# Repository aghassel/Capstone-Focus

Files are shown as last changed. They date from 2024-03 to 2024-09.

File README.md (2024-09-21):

# AI-Enhanced Glasses for Individuals with Visual and Auditory Impairments

## Overview

This project aims to develop **AI-Enhanced Glasses**, codenamed **Focus**, designed to support individuals with visual and auditory impairments. The glasses offer real-time assistance for communication, navigation, and daily tasks, promoting greater independence and enhancing the quality of life for users. The design integrates state-of-the-art deep learning models and computer vision technologies to bridge the gap for individuals with sensory impairments.

<div align="center">
  <a href="https://github.com/aghassel/Focus-AI-Glasses/blob/main/images/prototype.png">
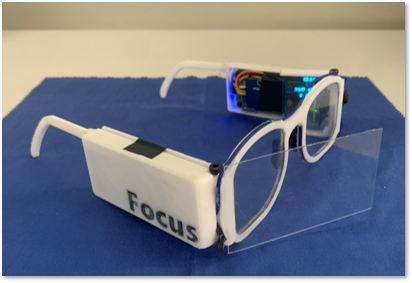
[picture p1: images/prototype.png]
Prototype
    
  </a>
</div>

---

## Key Features

<div align="center">
  
| Feature | Description |
|---|---|
| **Speech Translation & Transcription** | Converts speech to text and supports 133 languages. |
| **Sign Language Interpretation** | Translates ASL gestures into text and speech in real-time. |
| **Navigation Assistance** | Detects obstacles and provides alerts for oncoming objects. |
| **Health Monitoring** | Tracks heart rate and SpO2 levels in real-time. |
| **Real-time Q&A using LLMs** | Allows users to ask questions and get immediate responses. |
| **Battery Life** | Provides up to 5 hours of continuous usage. |

</div>

---

## Problem Statement

Globally, **1.1 billion** people experience some form of vision loss, with **285 million** having low vision or blindness. Additionally, **466 million** individuals suffer from hearing loss, while approximately **1 million** in the U.S. use American Sign Language (ASL) as their primary mode of communication.

<div align="center">
  <a href="https://github.com/aghassel/Focus-AI-Glasses/blob/main/images/stats_1.png" style="display:inline-block;">
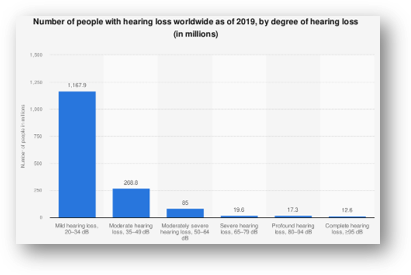
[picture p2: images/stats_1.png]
Stats 1
    
  </a>
  <a href="https://github.com/aghassel/Focus-AI-Glasses/blob/main/images/stats_2.jpg" style="display:inline-block;">
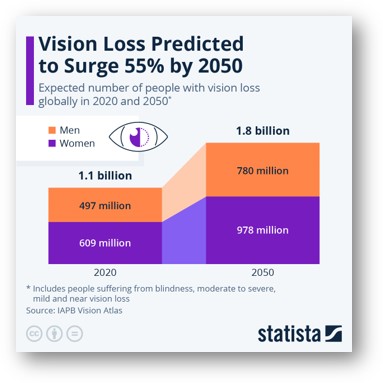
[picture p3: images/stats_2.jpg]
Stats 2
    
  </a>
</div>

---

## Solution Focus

The glasses are tailored to enhance the daily life of individuals with visual and auditory impairments by offering key features such as real-time performance and multimodal AI capabilities, ensuring users can access necessary support at any moment.

### Key Features:
- **Lightweight and Ergonomic Design**: Built for comfort with a five-hour battery life.
- **Speech Translation & Transcription**: Converts speech into text and offers multilingual translation support.
- **Sign Language Interpretation**: Translates ASL gestures into text and spoken words in real-time.
- **Navigation Assistance**: Alerts users to nearby obstacles and detects cars using object detection technology.
- **Health Monitoring**: Tracks health metrics like heart rate and SpO2 levels.
- **Real-Time Q&A**: Uses advanced language models for answering questions.
- **Real-Time Scheduling & Reminders**: Helps users manage daily tasks with reminders and schedules.
- **Weather & Date/Time Display**: Contextual information based on the user’s region.

<div align="center">
  <a href="https://github.com/aghassel/Focus-AI-Glasses/blob/main/images/architecture.png">
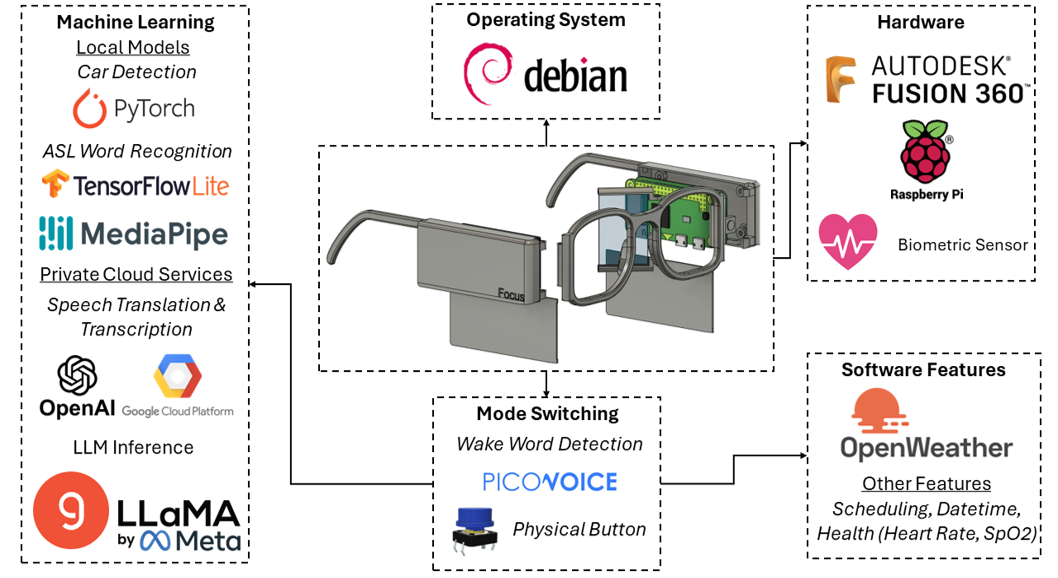
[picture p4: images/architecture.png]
    
  </a>
</div>

---

## Hardware Components

The glasses are designed with a robust yet lightweight platform using the following components:

- **Raspberry Pi Zero 2W**
- **1200mAh Pi Sugar (Battery Pack)**
- **Transparent OLED Screen**
- **Pi Spy Camera**
- **3D-Printed PLA Plastic Frame**
- **Biometric Sensors** for heart rate and SpO2 monitoring (MAX30100)
- **Texas Instruments USB Microphone**

The design overcomes power consumption and weight balance challenges by extending wires and optimizing battery placement to ensure comfort for long-duration wear.

---

## Software Architecture

### Core Technologies

- **Object Detection**: Uses **YOLOv5** model, trained on the COCO dataset for real-time object detection, achieving 95% accuracy on the Kitti dataset with 22ms inference speed.
- **Speech-to-Text & Translation**: Powered by **Google Cloud** with support for 133 languages, allowing fast and accurate speech recognition.
- **Text-to-Speech (TTS)**: Utilizes **OpenAI’s Whisper API** for realistic speech synthesis.
- **Large Language Models (LLMs)**: Utilizes **Llama2-70B** model for real-time query response, processing up to 350 tokens per second.
- **ASL Recognition**: Recognizes up to **250 ASL signs** using an ensemble of 1D Convolutional Neural Networks (1DCNN) and Transformer models, achieving **89% accuracy** with 17ms latency.

  <div align="center">
  <a href="https://github.com/aghassel/Focus-AI-Glasses/blob/main/images/asl_architecture.png">
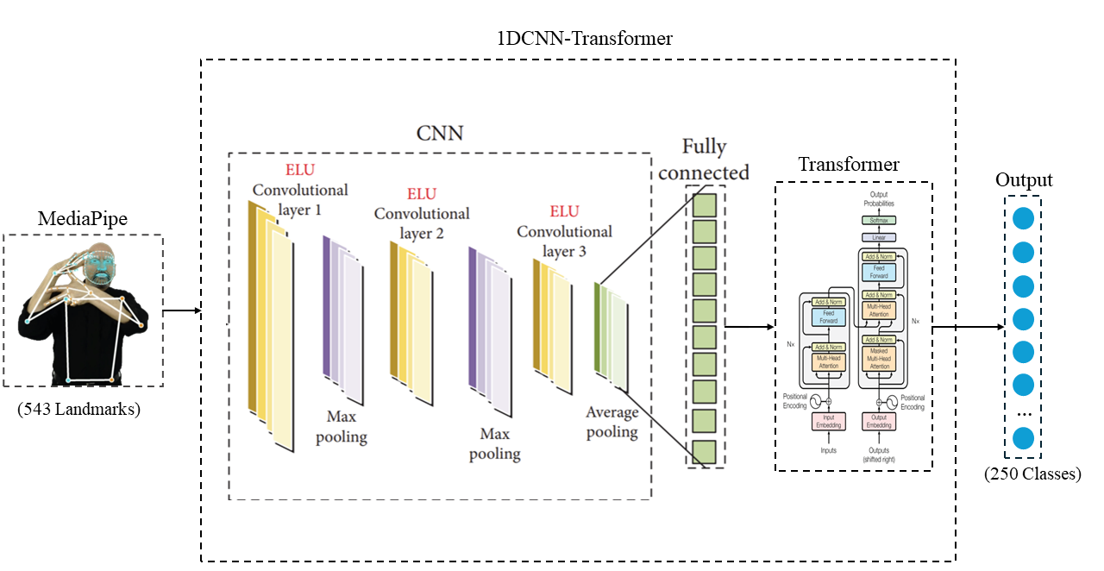
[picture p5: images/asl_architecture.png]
    
  </a>
</div>

### Car Detection

Utilizing the **YOLOv5 Architecture**, the glasses can detect nearby cars and highlight their locations with bounding boxes, providing real-time assistance to users in navigating their surroundings safely. This feature achieved **95% accuracy** using the **Intersection Over Union** metric on the **Kitti Dataset**.

<div align="center">
  <a href="https://github.com/aghassel/Focus-AI-Glasses/blob/main/images/cv_architecture.png">
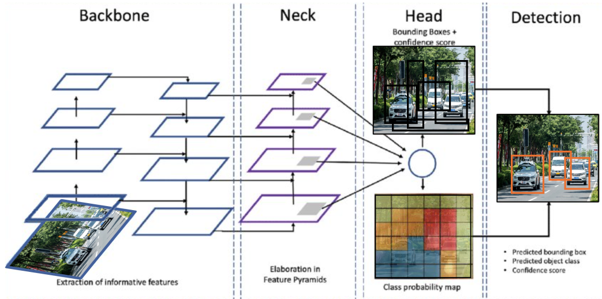
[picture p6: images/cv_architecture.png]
    
  </a>
</div>

---

## Construction & Design

The frame of the glasses is constructed using **3D-printed PLA plastic**, broken into multiple components (temples, hinges, and bridge) to facilitate the design. The challenge of balancing the weight from the battery pack was solved by extending wires and optimizing the placement of components for comfort and usability.

---

## Cost Breakdown

<div align="center">

| Component | Cost |
|---|---|
| Raspberry Pi Zero 2W | $28.99 |
| 1200mAh Pi Sugar | $45.99 |
| Texas Instruments USB Microphone | $10.00 |
| OLED Screen | $35.00 |
| Kuuleyn Raspberry Pi Camera | $10.00 |
| PLA Plastic | $0.30  |
| **Total** | **$130.28** |

</div>

---

## Evaluation Matrix

Each feature of the glasses is evaluated based on functionality, performance, usability, and innovation. Here's a summary of the evaluation criteria:

<div align="center">

| Feature | Functionality | Performance | Usability | Innovation |
|---|---|---|---|---|
| Designed for Accessibility | 4.5 | N/A | 4 | 3.5 |
| User-Friendly Design | 4 | N/A | 3.5 | 3.5 |
| Battery Life | 3.5 | 4 | 3.5 | 4.5 |
| Speech Translation | 5 | 4.5 | 4 | 4.5 |
| Sign Language Translation | 5 | 4 | 3.5 | 4 |
| Navigation Assistance | 4.5 | 4.5 | 4 | 4 |
| Instant Q&A using LLMs | 4 | 5 | 4.5 | 5 |
| Real-time Processing | 5 | 5 | 4 | 5 |

</div>

---

## Future Work

### Planned Enhancements:
- **Custom Printed Circuit Board (PCB)**: To reduce the size of the glasses and improve aesthetics.
- **Advanced Computing**: Transition to **NVIDIA Jetson** for enhanced AI performance.
- **Expanded Sign Language Support**: Extend the model to interpret full sentences and additional languages.
- **Display Upgrades**: Explore full glass lenses or micro projectors for enhanced user experience.
- **Car Detection Improvements**: Expand the detection model to include sidewalk identification for enhanced navigation assistance.

---

## References

- [1] Canadian Association of Optometrists. (2020). World Vision Facts from IAPB.
- [2] Government of Canada. (2021). "Hearing health of Canadian adults."
- [3] R. E. Mitchell and T. A. Young. "How Many People Use Sign Language?" The Journal of Deaf Studies and Deaf Education, 2023.
- [4] Google Isolated Sign Language Recognition. (2023). Kaggle.
- [5] Sohn H. (2023). Google Isolated Sign Language Recognition—1st Place Solution.
- [6] Geiger A., Lenz P., Stiller C., & Urtason R. (2013). "Vision meets Robotics: The KITTI Dataset." IJRR.

---

## License

This project is licensed under the MIT License. See [LICENSE](LICENSE) for more details.

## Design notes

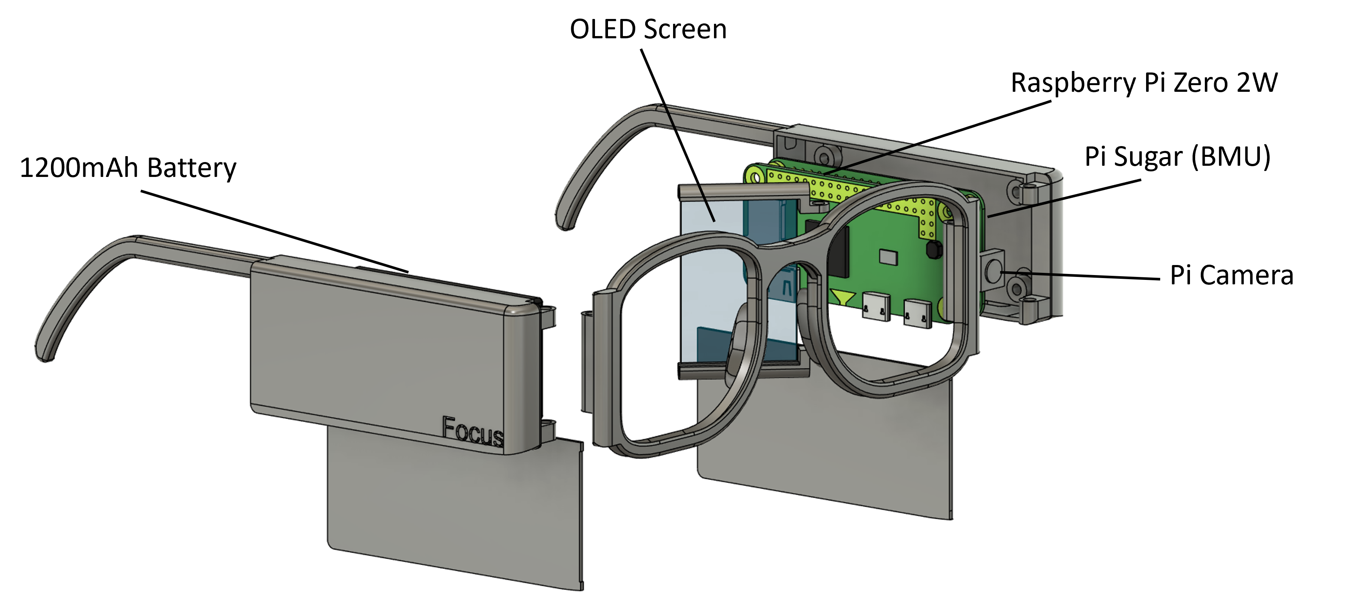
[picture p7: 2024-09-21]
images/hardware.png

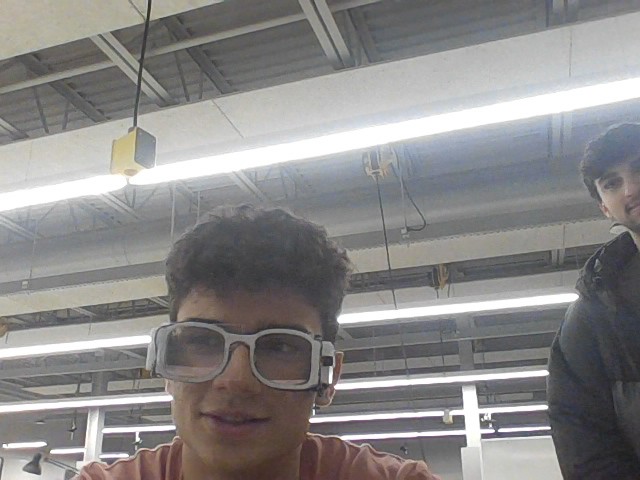
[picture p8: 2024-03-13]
output.jpg

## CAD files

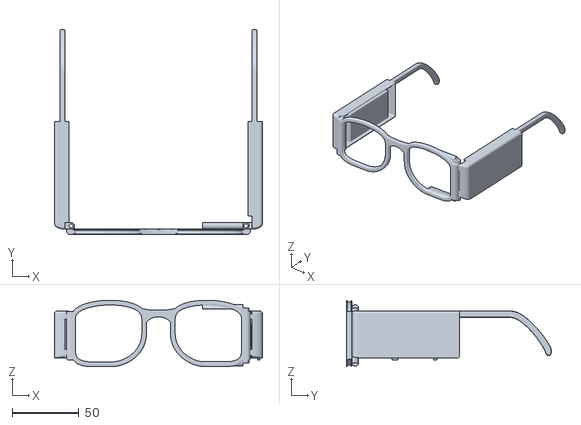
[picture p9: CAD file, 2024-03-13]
model/full-model.stl
156.3 x 154.0 x 49.9

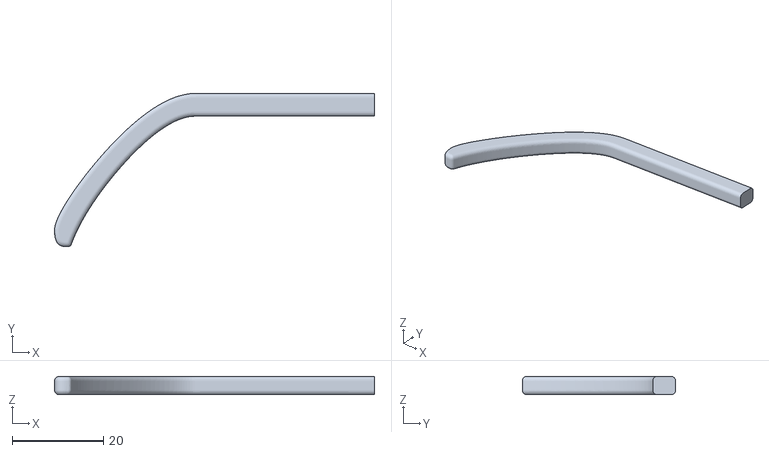
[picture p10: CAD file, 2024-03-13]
model/parts/left-ear-hook.stl
70.0 x 33.5 x 4.00

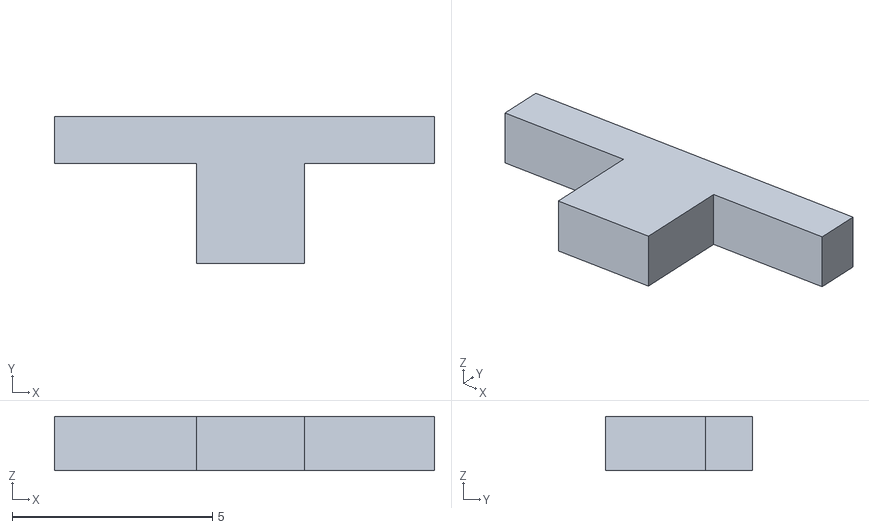
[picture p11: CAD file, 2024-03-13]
model/parts/switch.stl
9.50 x 3.68 x 1.36

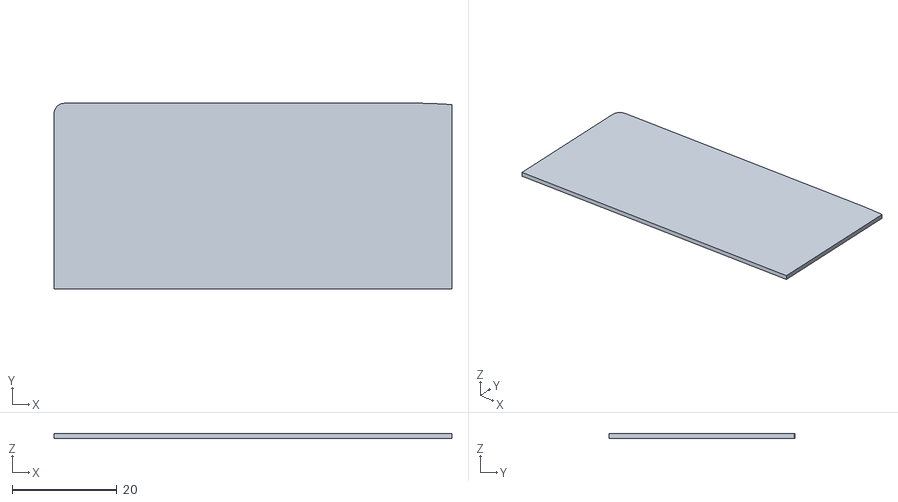
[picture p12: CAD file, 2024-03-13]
model/parts/right-lid.stl
76.0 x 35.4 x 1.00

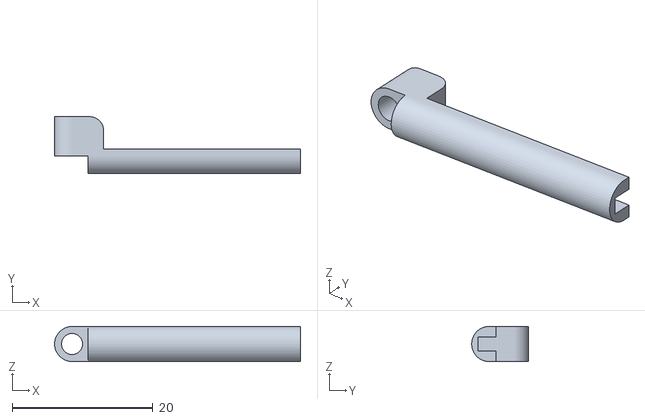
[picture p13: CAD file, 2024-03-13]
model/parts/oled-holder-lower.stl
35.0 x 8.07 x 5.00

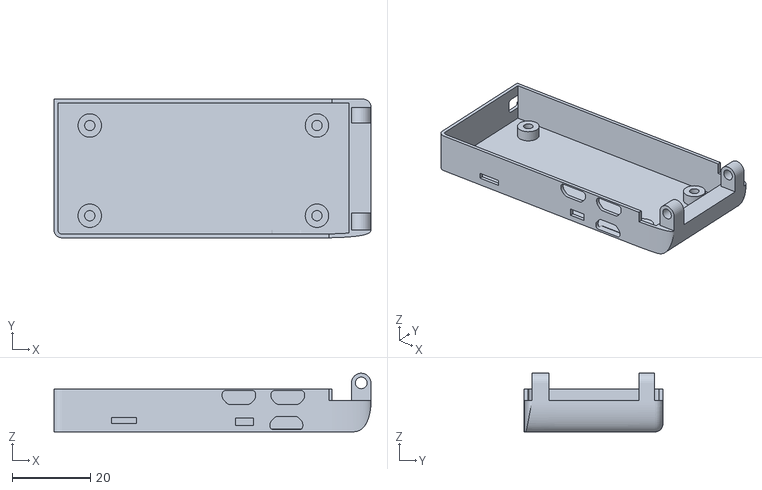
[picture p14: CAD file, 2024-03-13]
model/parts/left-container.stl
81.0 x 35.4 x 15.0

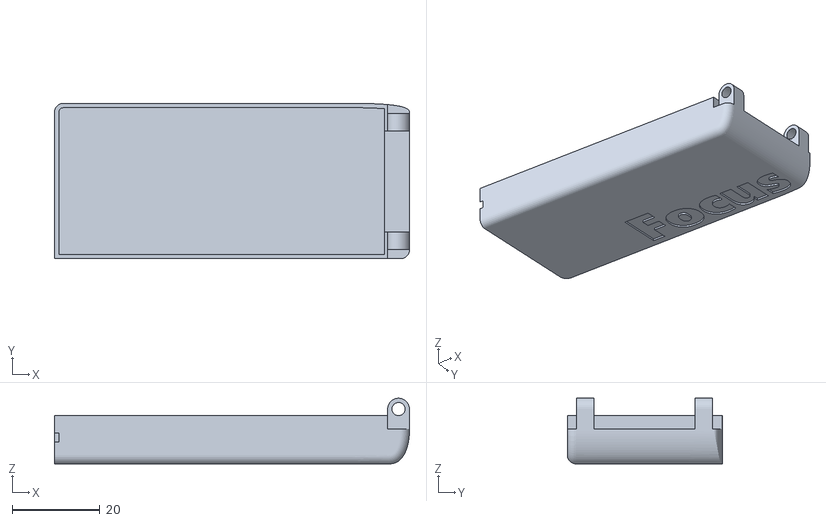
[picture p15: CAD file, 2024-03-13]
model/parts/right-container.stl
81.0 x 35.4 x 15.0

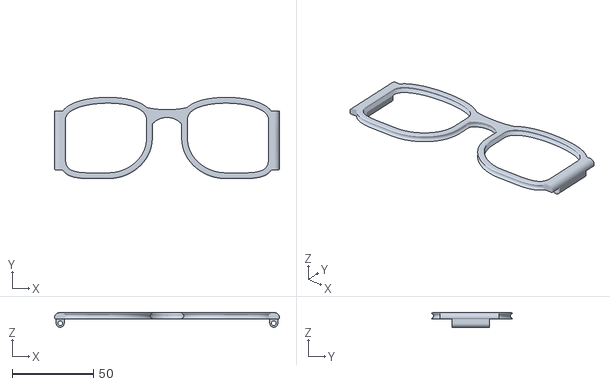
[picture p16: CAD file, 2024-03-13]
model/parts/front.stl
138.3 x 49.9 x 9.00

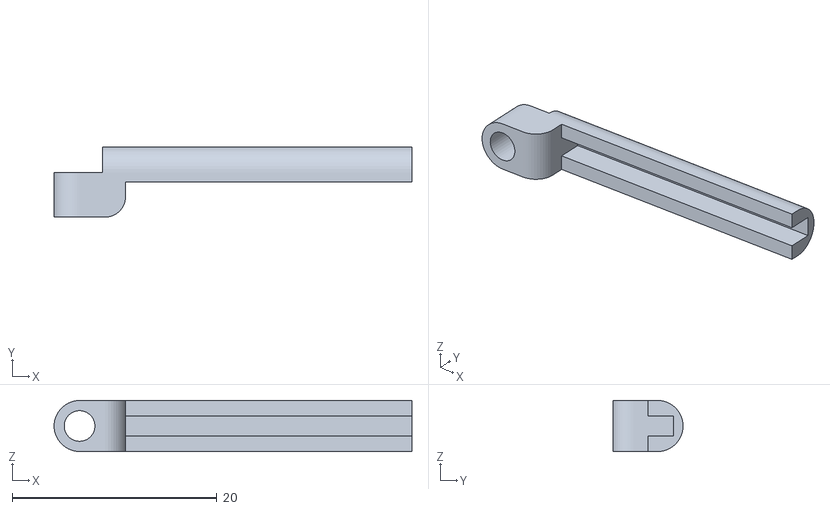
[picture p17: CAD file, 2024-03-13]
model/parts/oled-holder-upper.stl
35.0 x 6.87 x 5.00

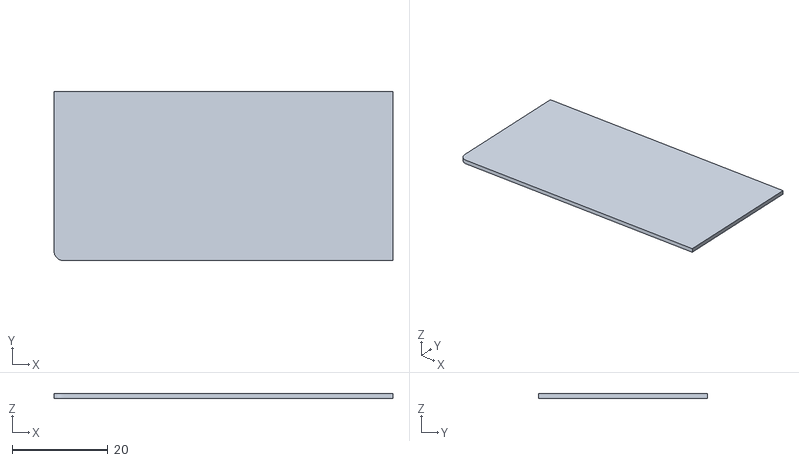
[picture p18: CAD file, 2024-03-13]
model/parts/left-lid.stl
71.0 x 35.4 x 1.00

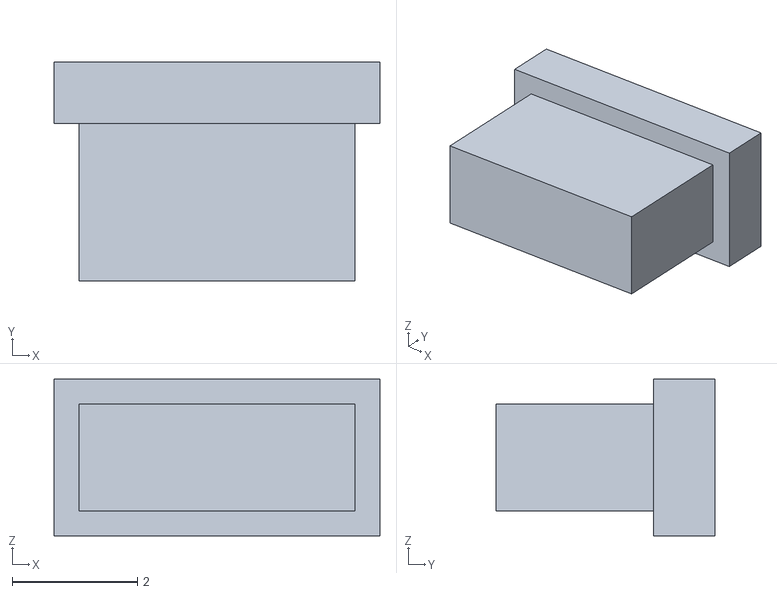
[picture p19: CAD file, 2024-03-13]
model/parts/button.stl
5.20 x 3.50 x 2.50

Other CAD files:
model/parts/right-ear-hook.stl
model/full-model.f3z

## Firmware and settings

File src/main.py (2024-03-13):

import asyncio
import signal
import threading
import pyaudio
import wave
import numpy as np
import websockets
import socket
import struct
from picamera2 import Picamera2
from picamera2.encoders import H264Encoder
from PIL import Image
from weather import weather
from schedule import get_schedule
from server import perform_asl_translation, asl_connection
from speech2text import speech_to_text
from question import question_mode
from wake_words import detect_wake_word, transcribe_audio, record_until_pause
from display import *
import time
import logging

import io
import socket
import struct
import asyncio
from display import display_asl_translation, display_img


# Initialize the PiCamera
picam = Picamera2()
recording = False

current_mode = 1
current_event_index = 0  # For schedule

global asl_conn

asl_conn = asl_connection()


async def take_picture():  # Take pic, flip it, then save
    camera_config = picam.create_still_configuration(main={"size": (1920, 1080)}, lores={"size": (640, 480)}, display="lores")
    picam.configure(camera_config)
    timestamp = time.strftime("%Y%m%d-%H%M%S")
    filename = f"/home/focus/image_{timestamp}.jpg"
    picam.start()
    picam.capture_file(filename)
    print(f"Picture saved as {filename}")
    img = Image.open(filename)
    img_rotated = img.rotate(90) 
    img_rotated.save(filename)
    display_text("Picture taken!")
    
    picam.stop()
    await asyncio.sleep(2)
    await display_mode_1_message() 


async def record_video(start=True):     # Take video
    global recording
    timestamp = time.strftime("%Y%m%d-%H%M%S")
    
    if start:
        video_config = picam.create_video_configuration(main={"size": (1920, 1080)}, lores={"size": (640, 480)}, display="lores")
        picam.configure(video_config)
        encoder = H264Encoder(bitrate=10000000)
        output = f"/home/focus/video_{timestamp}.h264"
        picam.start_recording(encoder, output)
        recording = True
        print("Recording started")
        display_text("Recording...\n\nHold to \nstop")
    else:
        picam.stop_recording()
        recording = False
        print("Recording stopped")
        display_text("Recording \nstopped\n\nVideo saved!")
        await asyncio.sleep(4) 
        await display_mode_1_message() 


async def display_weather_info():
    weather_info = await weather()
    print(weather_info)
    display_weather(weather_info)


def display_schedule_info(event_index=0):
    schedule_info = get_schedule()
    print(schedule_info)
    display_schedule(schedule_info, event_index)


async def display_mode_1_message():
    display_text("Tap to take pic \n\n Hold to start  video")


async def execute_mode_action():
    global current_mode
    global asl_
    if current_mode == 1:
        asl_conn.set_run(False)
        await display_mode_1_message()
    elif current_mode == 2:  # Weather
        asl_conn.set_run(False)
        await display_weather_info()
    elif current_mode == 3:  # Schedule
        asl_conn.set_run(False)
        display_schedule_info(current_event_index)
    elif current_mode == 4:  # Speech to Text
        asl_conn.set_run(False)
        display_text("Transcribing...")
        await speech_to_text()
    elif current_mode == 5: # ASL translation
        asl_conn.current_mode = "ASL"
        asl_conn.set_run(True)
        await asl_conn.running_loop(picam)
        asl_conn.set_run(False)
        # await perform_asl_translation(picam)
    elif current_mode == 6: # Object Detection
        asl_conn.set_run(False)
        asl_conn.current_mode = "CAR"
        asl_conn.set_run(True)
        await asl_conn.running_loop(picam)
        asl_conn.set_run(False)
    # elif current_mode == 7:   # Question Mode
    #     asl_conn.set_run(False)
    #     display_text("Question and answering...")
    #     record_until_pause()
    #     question = transcribe_audio("output.wav")
    #     print(question)
    #     answer = await question_mode(question)
    #     print(answer)
    #     display_text(answer)
    


async def listen_for_messages(uri):
    global current_mode, current_event_index
    async with websockets.connect(uri) as websocket:
        while True:
            message = await websocket.recv()
            print(f"Message received: {message}")
            if message == "double":
                asl_conn.run = False
                current_mode = (current_mode % 6) + 1  
                current_event_index = 0  # Reset the event index on mode change
                print(f"Mode changed to {current_mode}")
                await execute_mode_action()
            elif message == "single" and current_mode == 3:
                display_schedule_info(current_event_index)
                current_event_index += 1
            elif message == "long" and current_mode == 1:  # Video
                await record_video(start=not recording)
            elif message == "single" and current_mode == 1: # Pic
                await take_picture()
            


async def listen_for_wake_word_and_commands():
    global current_mode
    out_of_transcribe = True
    # global asl_conn
    while True:
        # Detect wake word
        await asyncio.get_event_loop().run_in_executor(None, detect_wake_word)
        print("Wake word detected! Listening for command...")

        while out_of_transcribe:
            display_text("Listening...")

            # Record command after wake word detection
            filename = await asyncio.get_event_loop().run_in_executor(None, record_until_pause)
            print(f"filename: {filename}")

            # Transcribe audio to text
            transcription = await asyncio.get_event_loop().run_in_executor(None, transcribe_audio, filename)
            
            if transcription:
                # Process transcription to execute the appropriate action
                transcription = transcription.replace(".", "").replace(",", "").replace("?", "").replace("!", "")
                transcription = transcription.replace(":", "").replace(";", "").lower()
                print(transcription)

                # Process command
                if "picture" in transcription:
                    asl_conn.set_run(False)
                    current_mode = 1
                    await take_picture()
                    break
                elif "video" in transcription:
                    asl_conn.set_run(False)
                    current_mode = 1
                    await record_video(start=True)  # Assuming you want to start recording immediately
                    break
                # Add more elif blocks for other commands like "weather", "schedule", etc.
                elif "weather" in transcription:
                    asl_conn.set_run(False)
                    current_mode = 2
                    await display_weather_info()
                    break
                elif "schedule" in transcription:
                    asl_conn.set_run(False)
                    current_mode = 3
                    display_schedule_info(current_event_index)
                    break
                elif "transcribe" in transcription:
                    asl_conn.set_run(False)
                    current_mode = 4
                    display_text("Transcribing...")
                    await speech_to_text()
                elif "sign language" in transcription:
                    current_mode = 5
                    asl_conn.current_mode = "ASL"
                    asl_conn.set_run(True)
                    await asl_conn.running_loop(picam)
                    asl_conn.set_run(False)
                    break
                    # await perform_asl_translation(picam)
                elif "object detection" in transcription: # Object Detection
                    asl_conn.set_run(False)
                    asl_conn.current_mode = "CAR"
                    asl_conn.set_run(True)
                    await asl_conn.running_loop(picam)
                    asl_conn.set_run(False)
                    break

                elif "question" in transcription:
                    asl_conn.run = False
                    current_mode = 6
                    display_text("Question and answering...\n\n\nWhat is your question?")
                    record_until_pause()
                    question = transcribe_audio("output.wav")
                    print(question)
                    answer = await question_mode(question)
                    print(answer)
                    display_text(answer)
                    break
                    #tts(answer)
                else:
                    display_text("Unknown command. Please try again.")
                    break


# Display a startup logo
#logo_path = '/path/to/your/logo.png'  # Update the path to your logo
#display_logo(logo_path)

# WebSocket URI
uri = "ws://0.0.0.0:8422"
async def runstt():
    await asyncio.gather(
        speech_to_text(),
        listen_for_messages("ws://0.0.0.0:8422")
    )

"""async def main():
    # Set up your asyncio tasks here
    task1 = asyncio.create_task(listen_for_messages(uri))
    task2 = asyncio.create_task(listen_for_wake_word_and_commands())

    # Function to handle cancellation so tasks can be cancelled gracefully
    def signal_handler():
        task1.cancel()
        task2.cancel()

    # Registering signal handlers for graceful shutdown
    loop = asyncio.get_running_loop()
    for sig in (signal.SIGINT, signal.SIGTERM):
        loop.add_signal_handler(sig, signal_handler)

    try:
        # Instead of waiting for both tasks to complete, enter an infinite loop
        while True:
            # Sleep for a long time (effectively forever) without blocking
            await asyncio.sleep(3600)  # Sleep for 1 hour
    except asyncio.CancelledError:
        # If the loop or tasks are cancelled, ensure everything is stopped gracefully
        pass
    finally:
        # Wait for tasks to be cancelled
        await task1
        await task2

# Running the asyncio event loop
asyncio.run(main())"""

async def main():
    try:
        # As before, with logging added to tasks and signal handling
        logging.info("Starting main event loop")
        task1 = asyncio.create_task(listen_for_messages(uri))
        task2 = asyncio.create_task(listen_for_wake_word_and_commands())

        def signal_handler():
            task1.cancel()
            task2.cancel()
            logging.info("Signal received, shutting down gracefully")

        loop = asyncio.get_running_loop()
        for sig in (signal.SIGINT, signal.SIGTERM):
            loop.add_signal_handler(sig, signal_handler)

        while True:
            await asyncio.sleep(3600)
    except asyncio.CancelledError:
        logging.info("Tasks cancelled")
    finally:
        await task1
        await task2
        logging.info("Clean shutdown complete")


asyncio.run(main())

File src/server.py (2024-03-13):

import io
import socket
import struct
from picamera2 import Picamera2
import asyncio
from display import *
from PIL import Image
import websockets

class asl_connection():
    def __init__(self):
        self.run = False
        self.server_ip = '192.168.2.74'
        self.server_port = 8000
        self.current_mode = "ASL"
        print("init")

    def startup(self, picam2):
        print("startup")
        self.picam2 = picam2
        # Create a non-blocking socket
        self.client_socket = socket.socket()    
        # Picamera2 setup is already provided in the argument
        self.camera_config = self.picam2.create_still_configuration(main={"size": (640, 480)})
        self.picam2.configure(self.camera_config)
        self.picam2.start()
    
    def set_run(self, mode):
        print("run: ", mode)
        self.run = mode
    
    async def running_loop(self, picam2):
        print("rinning")
        self.startup(picam2)
        print("startup complete")
        
        self.client_socket.connect((self.server_ip, self.server_port))
        
        # await asyncio.get_event_loop().sock_connect(self.client_socket, (self.server_ip, self.server_port))
        try:
            while self.run:
                self.picam2.capture_file("temp.jpg")  # Temporarily capture to a file
                with Image.open("temp.jpg") as img:
                    rotated_img = img.rotate(90, expand=True)  # `expand=True` to resize the image to fit the new orientation
                    rotated_img.save("temp.jpg")  # Overwrite the original image with the rotated one

                with open("temp.jpg", "rb") as image_file:
                    image_data = image_file.read()
                    mode_message = self.current_mode.encode('utf-8')
                    mode_header = struct.pack('<BI', 0, len(mode_message))  # Message type 0, length of mode message
                    image_header = struct.pack('<BI', 1, len(image_data))  # Message type 1, length of image data
                    
                    # Send mode message
                    # await asyncio.get_event_loop().sock_sendall(self.client_socket, mode_header + mode_message)
                    self.client_socket.sendall(mode_header + mode_message)
                    
                    # Send image data
                    # await asyncio.get_event_loop().sock_sendall(self.client_socket, image_header + image_data)
                    self.client_socket.sendall(image_header + image_data)
                    
                    # prediction = await asyncio.get_event_loop().sock_recv(client_socket, 1024)
                    prediction = self.client_socket.recv(1024)
                    if self.current_mode == "ASL":
                        prediction_text = prediction.decode('utf-8')
                        # Split the prediction to extract the word part only
                        word, _ = prediction_text.split(',', 1)  # This assumes the format "word, confidence"
                        print(f"Received prediction: {prediction_text}")
                        
                        # Display only the word part of the ASL translation
                        display_text(word.strip())  # 
                        await asyncio.sleep(0)
                    if self.current_mode == "CAR":
                        prediction_text = prediction.decode('utf-8')
                        # Split the prediction to extract the word part only
                        print(f"Received prediction: {prediction_text}")
                        
                        # Display only the word part of the ASL translation
                        display_text(prediction_text) 
                        # image = Image.frombytes('RGBA', prediction)
                        # display_img(image)
                        # image.save("testst.jpg")
                        await asyncio.sleep(0)
            self.client_socket.close()
            self.picam2.stop()    
            
        finally:
            self.client_socket.close()
            self.picam2.stop()
    
    def close_server(self):
        self.set_run(False)
        self.client_socket.close()
        self.picam2.stop()


class server_connection():
    def __init__(self):
        self.run = False
        self.server_ip = '192.168.2.74'
        self.server_port = 8000
        self.current_mode = "ASL"
        print("init")

    def startup(self, picam2):
        print("startup")
        self.picam2 = picam2
        # Create a non-blocking socket
        self.client_socket = socket.socket()    
        # Picamera2 setup is already provided in the argument
        self.camera_config = self.picam2.create_still_configuration(main={"size": (640, 480)})
        self.picam2.configure(self.camera_config)
        self.picam2.start()
    
    def set_run(self, mode):
        print("run: ", mode)
        self.run = mode
    
    def running_loop(self, picam2):
        print("rinning")
        self.startup(picam2)
        print("startup complete")
        
        self.client_socket.connect((self.server_ip, self.server_port))
        
        # await asyncio.get_event_loop().sock_connect(self.client_socket, (self.server_ip, self.server_port))
        try:
            self.picam2.capture_file("temp.jpg")  # Temporarily capture to a file
            with Image.open("temp.jpg") as img:
                rotated_img = img.rotate(90, expand=True)  # `expand=True` to resize the image to fit the new orientation
                rotated_img.save("temp.jpg")  # Overwrite the original image with the rotated one
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

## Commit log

2024-03-10 Main code for Raspberry Pi
2024-03-10 Resize frame and bounding box coordinates for car detection
2024-03-13 fixed features, added object detection
    [display.py, main.py, question.py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]
